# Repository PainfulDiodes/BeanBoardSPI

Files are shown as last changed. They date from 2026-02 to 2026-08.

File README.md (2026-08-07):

# BeanBoardSPI

_SPI controller in 74' logic for [BeanBoard](https://github.com/PainfulDiodes/BeanBoard) / [BeanZee](https://github.com/PainfulDiodes/BeanZee) Z80 computer._

SPI is a fast serial interface commonly used for connecting microcontrollers to peripherals like SD cards, displays and sensors.

The intent of this design is to provide access to an [RA8875](https://www.adafruit.com/product/1590) TFT panel controller and to [flash memory modules](https://www.adafruit.com/product/5635) on my Z80 homebrew computer. The [Marvin](https://github.com/PainfulDiodes/marvin) monitor program provides software support for this configuration.

For background, please see the [accompanying blog posts](https://painfuldiodes.wordpress.com/category/beanboardspi/).

*Thank you to those helpful folks at [PCBWay](https://pcbway.com) who sponsored this build and provided the PCBs*

&nbsp;

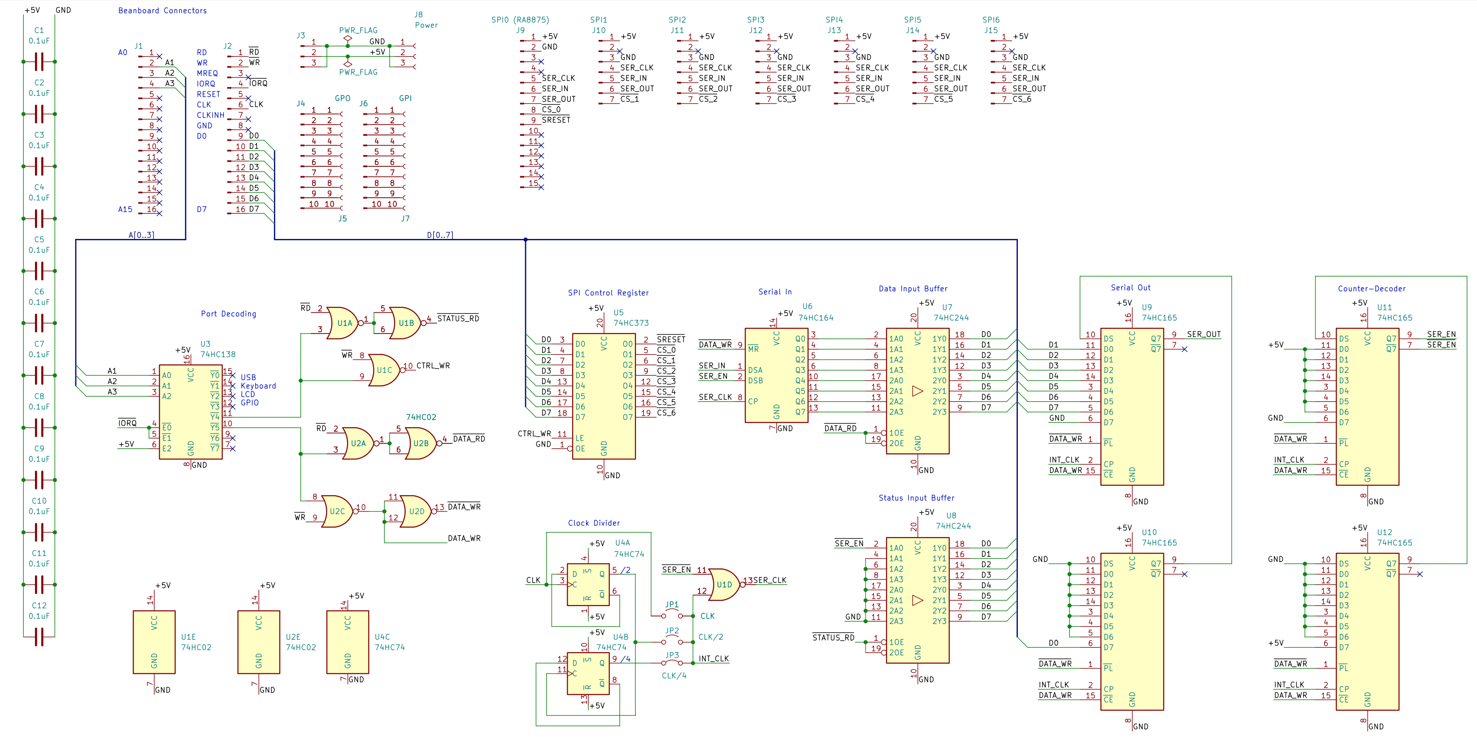
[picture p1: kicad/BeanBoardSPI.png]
beanboardspi-schematic


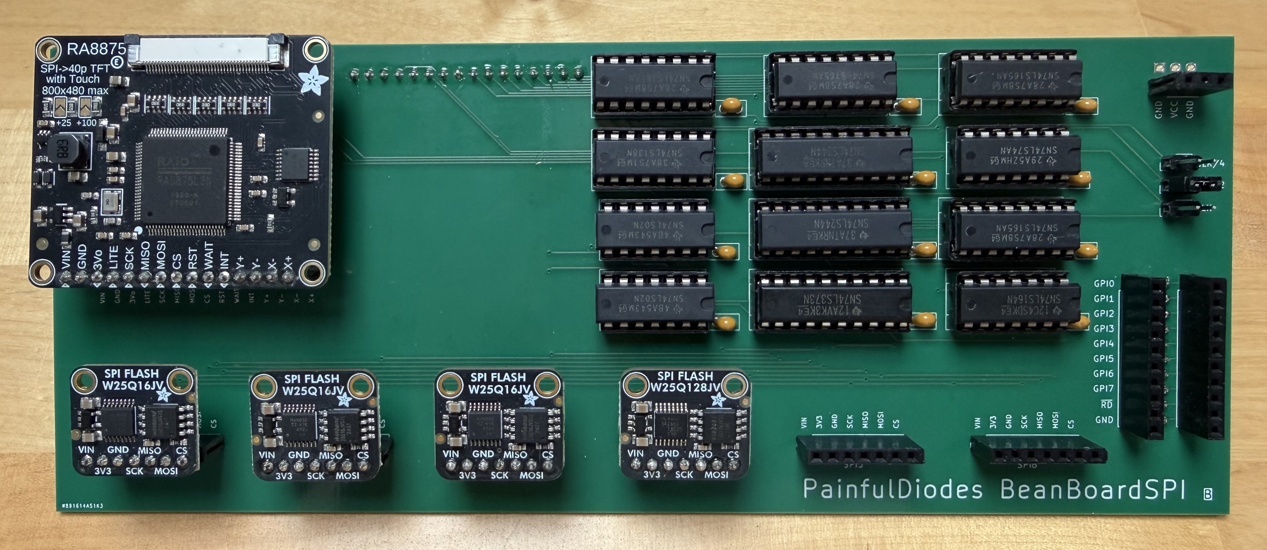
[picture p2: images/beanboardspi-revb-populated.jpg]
beanboardspi-revb-populated

BeanBoardSPI Rev B populated with Adafruit SPI modules

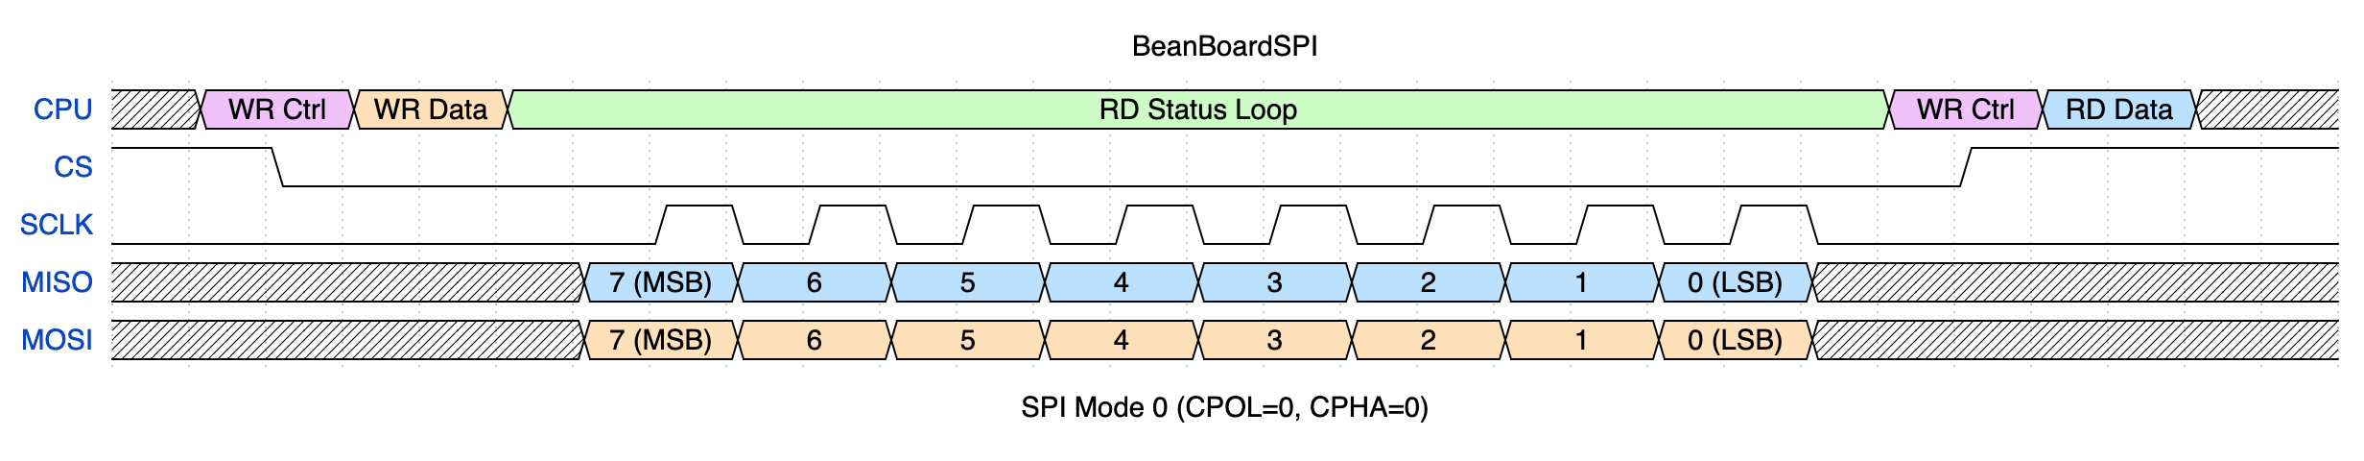
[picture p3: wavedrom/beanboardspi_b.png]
wavedrom-timing-diagram

SPI timing

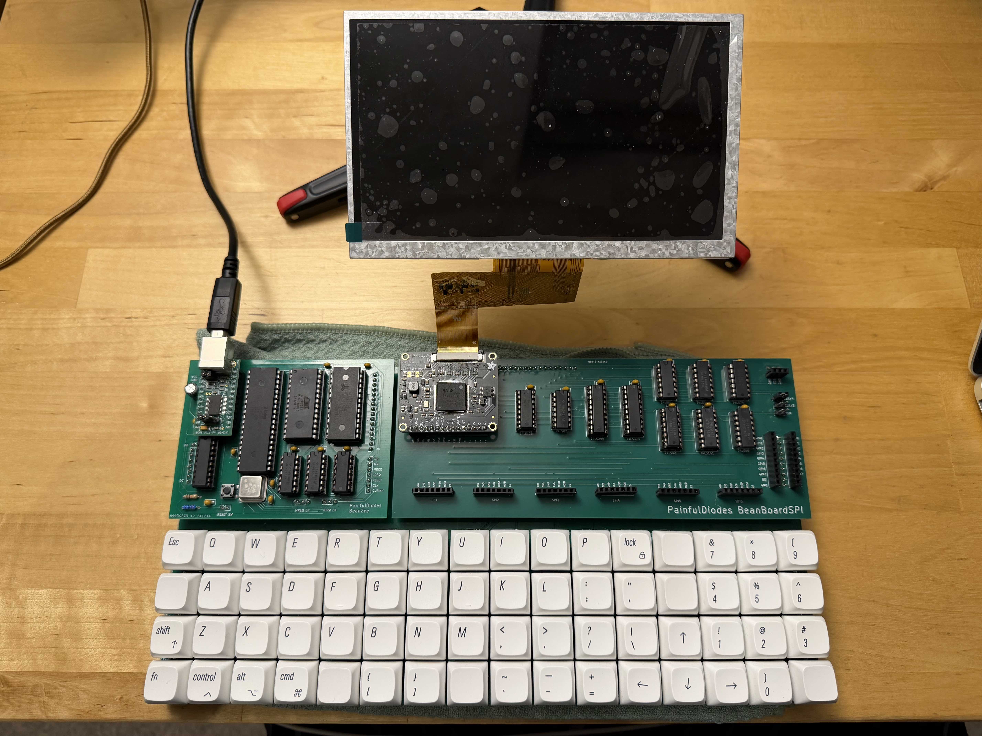
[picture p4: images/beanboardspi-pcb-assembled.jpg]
beanboard-spi-pcb-assembled

BeanBoardSPI Rev A Plugged into BeanBoard with BeanZee, and a TFT panel

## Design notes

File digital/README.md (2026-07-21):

# Digital simulations

These .dig files were designed and may be run in [Digital](https://github.com/hneemann/Digital)

Helmut Neemann's Digital is an excellent and easy-to-use digital logic designer and circuit simulator.

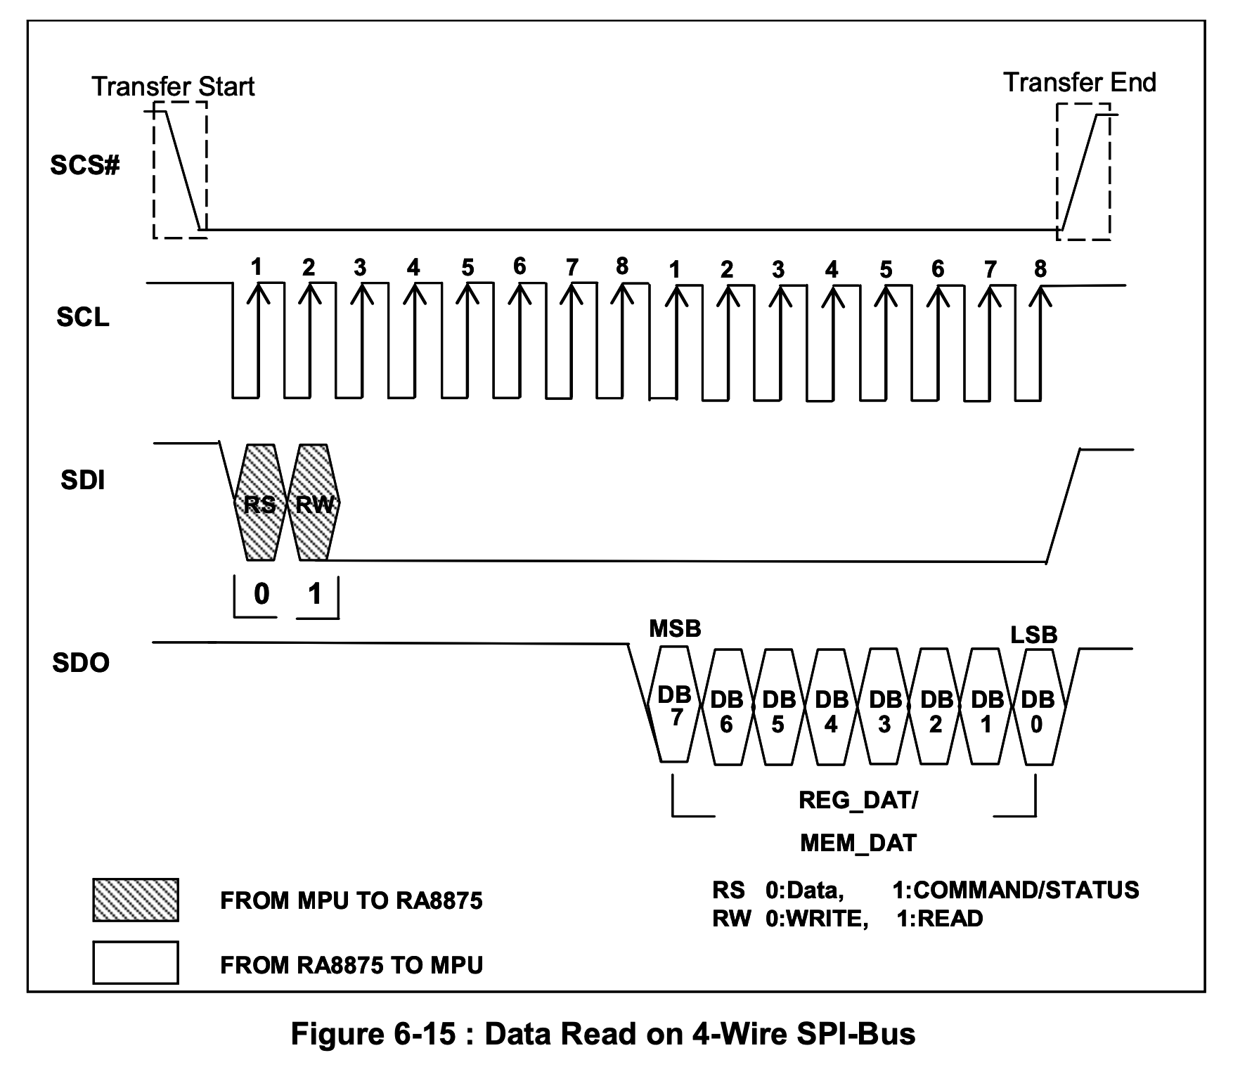
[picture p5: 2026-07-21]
images/ra8875_data_read.png

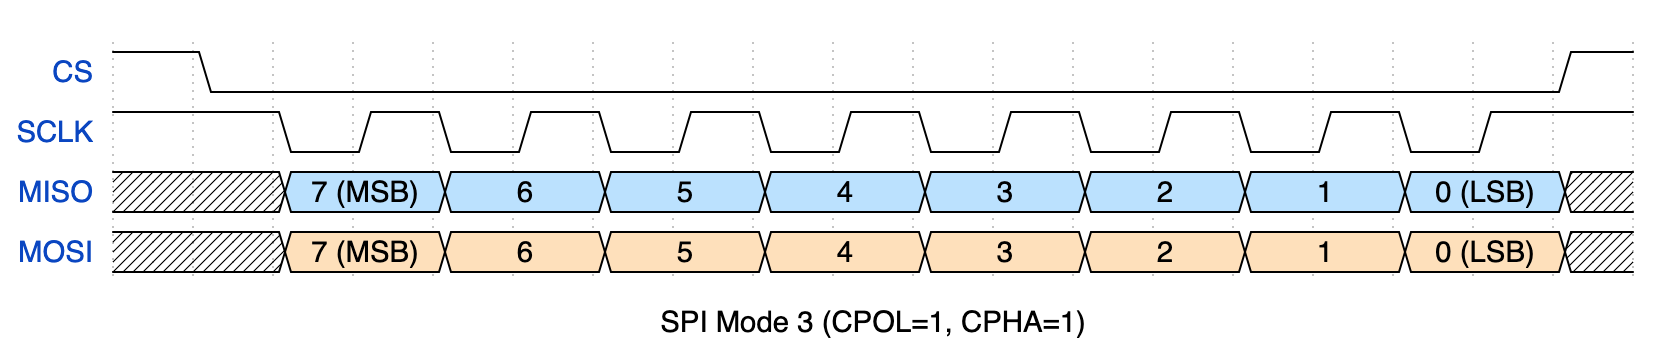
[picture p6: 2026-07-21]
wavedrom/spi_mode_3.png

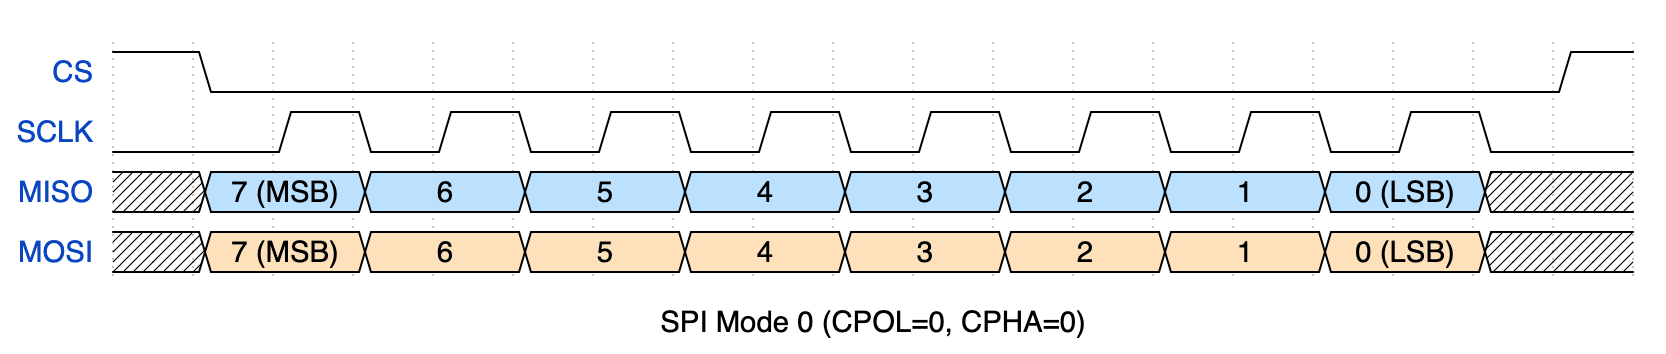
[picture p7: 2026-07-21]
wavedrom/spi_mode_0.png

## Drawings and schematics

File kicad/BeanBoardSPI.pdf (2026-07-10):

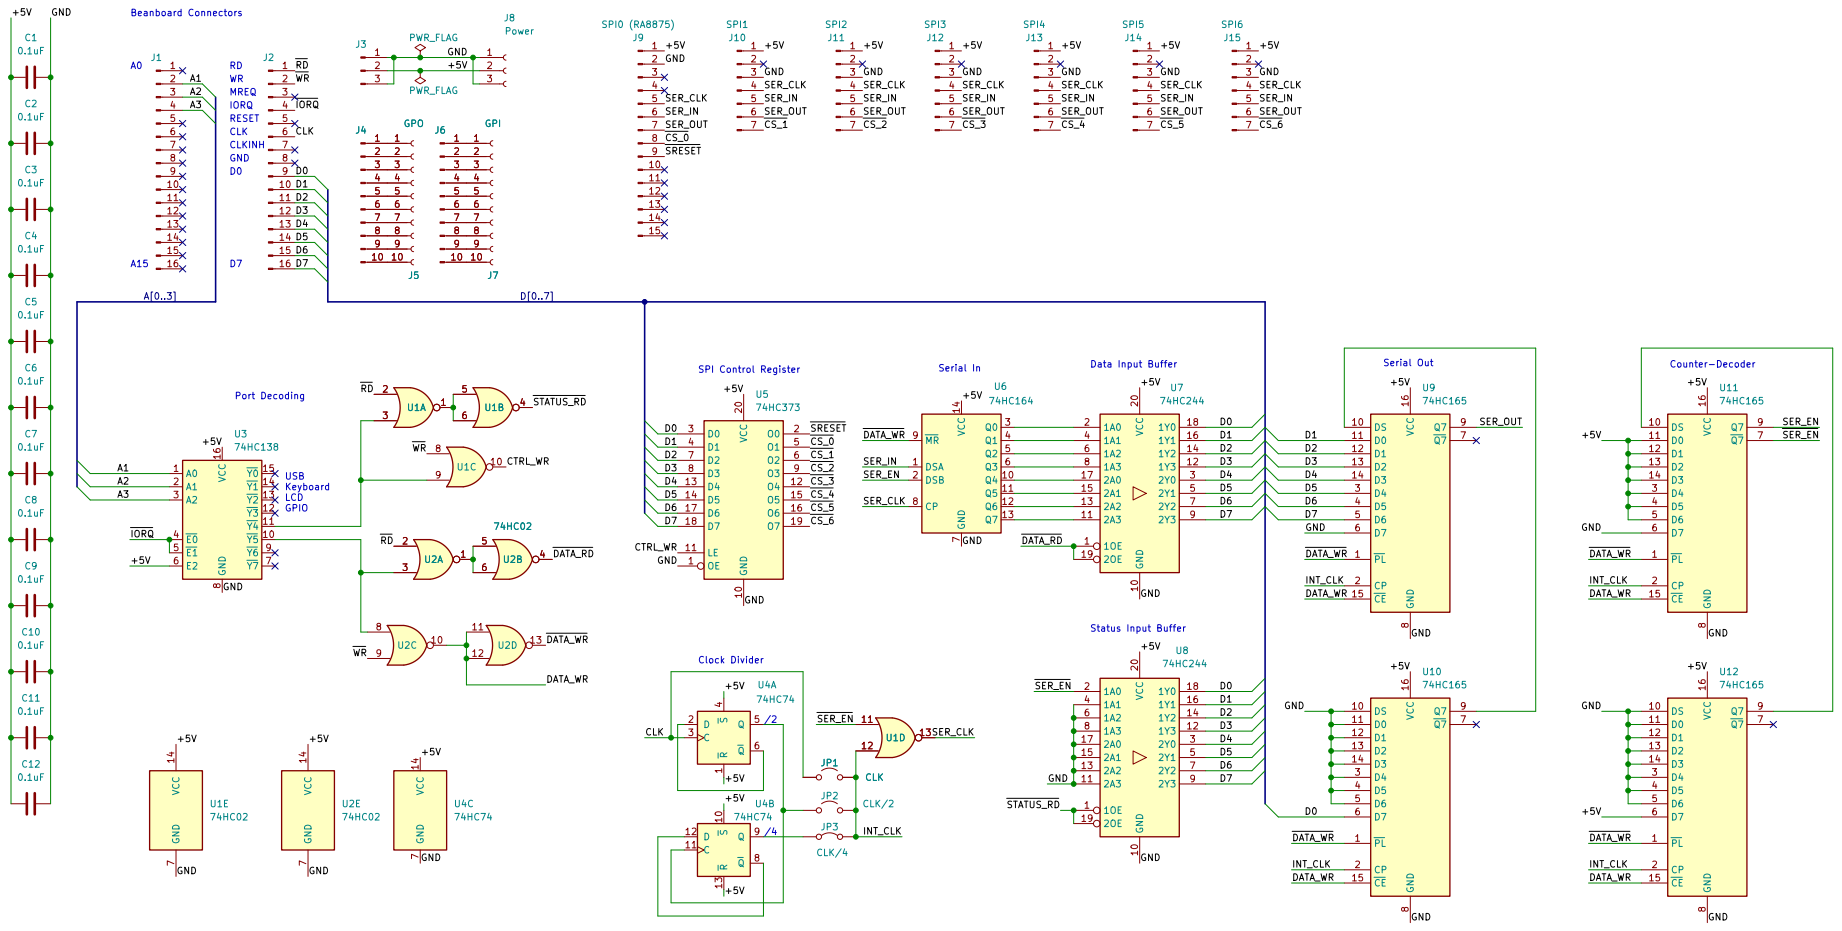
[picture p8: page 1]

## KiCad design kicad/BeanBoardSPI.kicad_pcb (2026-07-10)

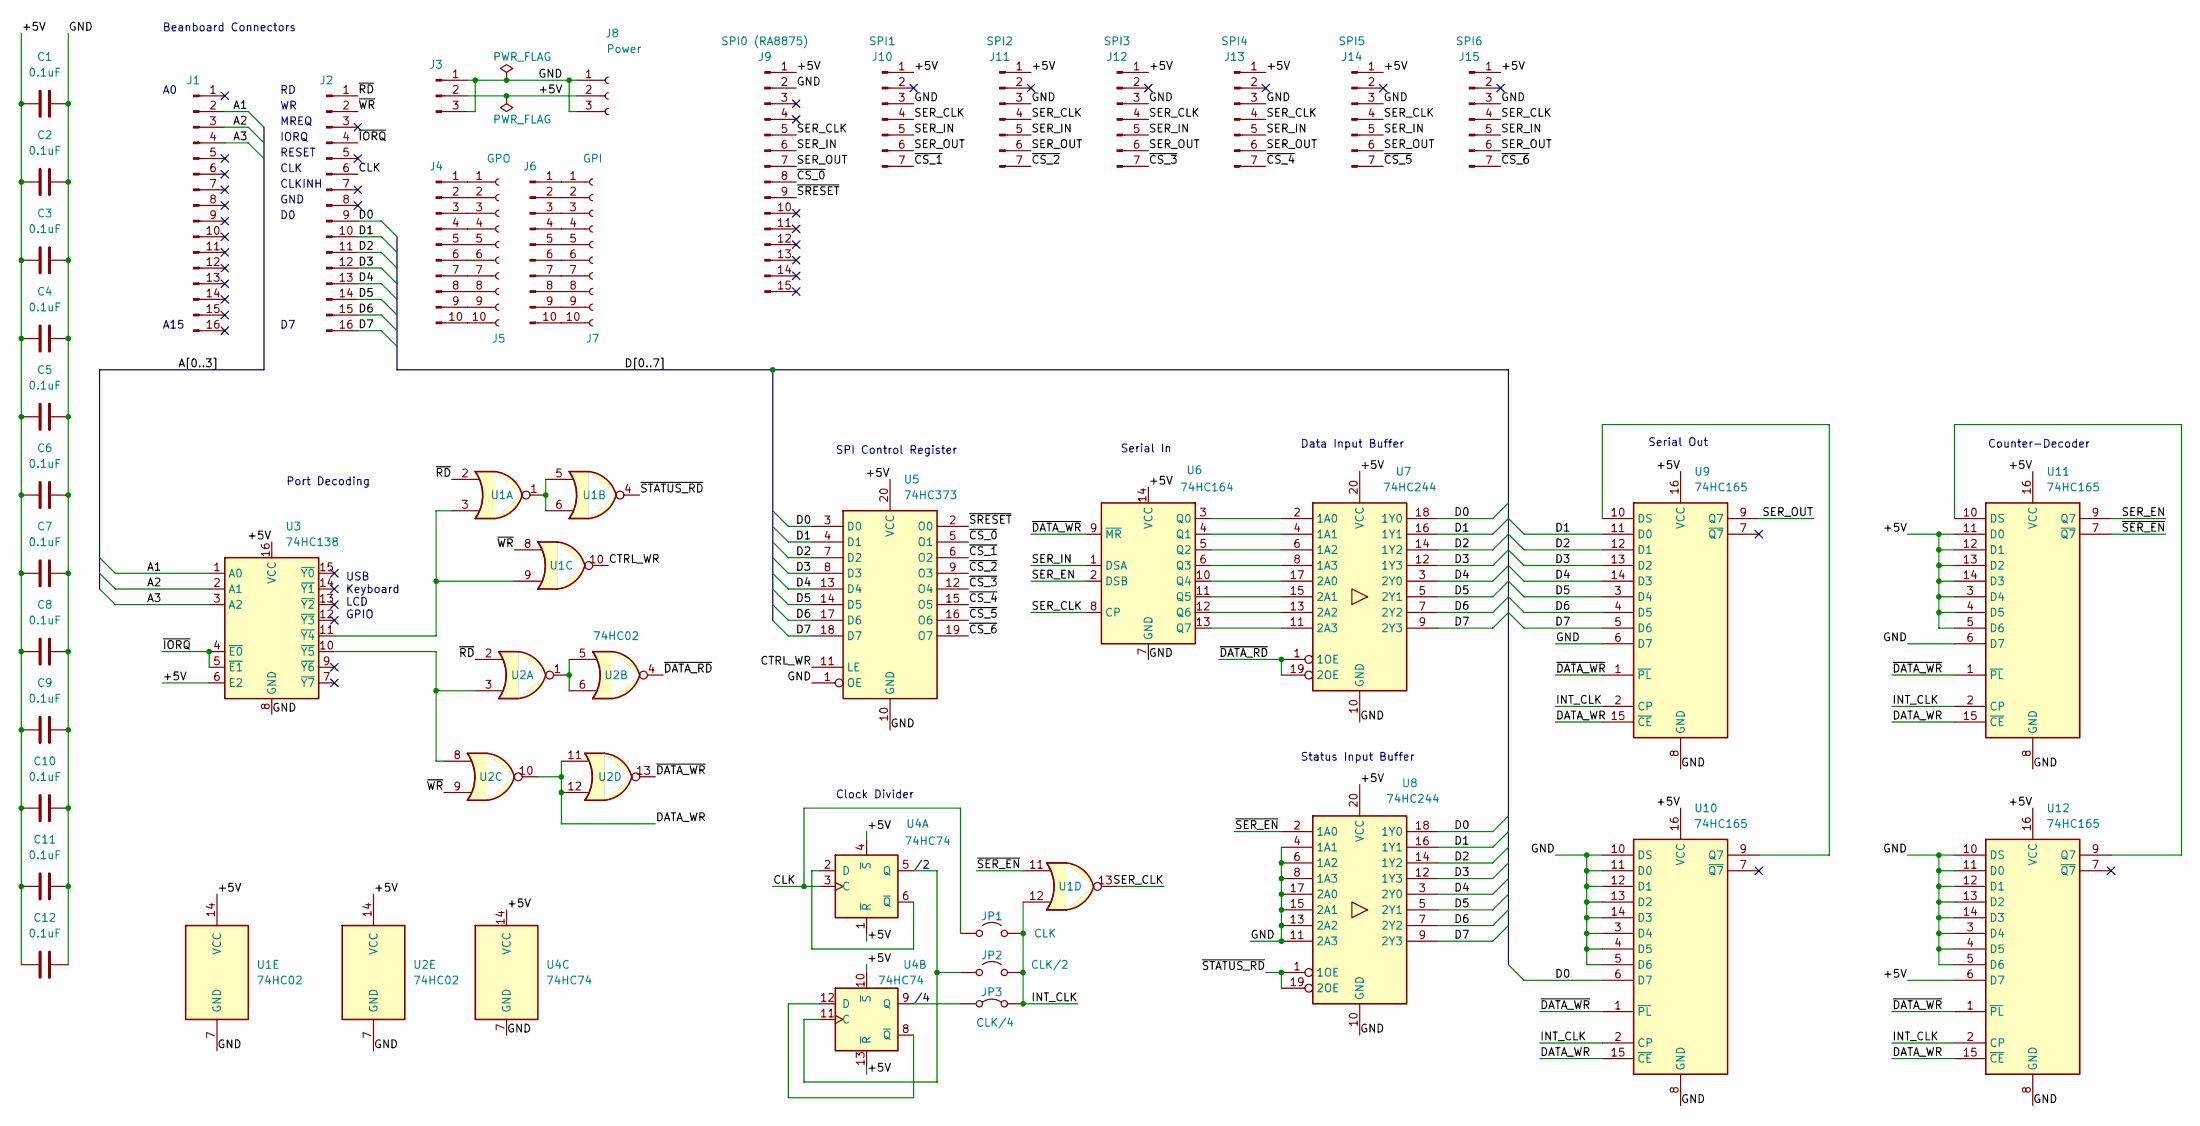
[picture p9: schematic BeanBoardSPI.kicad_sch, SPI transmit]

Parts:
C1, C2, C3, C4, C5, C6, C7, C8, C9, C10, C11, C12: 0.1uF; C_Disc_D5.0mm_W2.5mm_P2.50mm
J1, J2: Conn_01x16_Pin; PinHeader_1x16_P2.54mm_Vertical
J3: Conn_01x03_Pin; PinHeader_1x03_P2.54mm_Vertical
J4, J6: Conn_01x10_Pin; PinHeader_1x10_P2.54mm_Vertical
J5: GPO; PinSocket_1x10_P2.54mm_Vertical
J7: GPI; PinSocket_1x10_P2.54mm_Vertical
J8: Power; PinSocket_1x03_P2.54mm_Vertical
J9: SPI0 (RA8875); PinHeader_1x15_P2.54mm_Vertical
J10: SPI1; PinHeader_1x07_P2.54mm_Vertical
J11: SPI2; PinHeader_1x07_P2.54mm_Vertical
J12: SPI3; PinHeader_1x07_P2.54mm_Vertical
J13: SPI4; PinHeader_1x07_P2.54mm_Vertical
J14: SPI5; PinHeader_1x07_P2.54mm_Vertical
J15: SPI6; PinHeader_1x07_P2.54mm_Vertical
JP1: CLK; PinHeader_1x02_P2.54mm_Vertical
JP2: CLK/2; PinHeader_1x02_P2.54mm_Vertical
JP3: CLK/4; PinHeader_1x02_P2.54mm_Vertical
U1, U2: 74HC02; DIP-14_W7.62mm_Socket
U3: 74HC138; DIP-16_W7.62mm_Socket
U4: 74HC74; DIP-14_W7.62mm_Socket
U5: 74HC373; DIP-20_W7.62mm_Socket
U6: 74HC164; DIP-14_W7.62mm_Socket
U7, U8: 74HC244; DIP-20_W7.62mm_Socket
U9, U10, U11, U12: 74HC165; DIP-16_W7.62mm_Socket

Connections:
/+5V: C1.1, C2.1, C3.1, C4.1, C5.1, C6.1, C7.1, C8.1, C9.1, C10.1, C11.1, C12.1, J3.2, J8.2, J9.1, J10.1, J11.1, J12.1, J13.1, J14.1, J15.1, U1.14 (VCC), U2.14 (VCC), U3.6 (E2), U3.16 (VCC), U4.1 (~R), U4.4 (~S), U4.10 (~S), U4.13 (~R), U4.14 (VCC), U5.20 (VCC), U6.14 (VCC), U7.20 (VCC), U8.20 (VCC), U9.16 (VCC), U10.16 (VCC), U11.3 (D4), U11.4 (D5), U11.5 (D6), U11.11 (D0), U11.12 (D1), U11.13 (D2), U11.14 (D3), U11.16 (VCC), U12.6 (D7), U12.16 (VCC)
/A1: J1.2, U3.1 (A0)
/A2: J1.3, U3.2 (A1)
/A3: J1.4, U3.3 (A2)
/CLK: J2.6, JP1.1 (A), U4.3 (C)
/CTRL_WR: U1.10, U5.11 (LE)
/D0: J2.9, U5.3 (D0), U7.18 (1Y0), U8.18 (1Y0), U10.6 (D7)
/D1: J2.10, U5.4 (D1), U7.16 (1Y1), U8.16 (1Y1), U9.11 (D0)
/D2: J2.11, U5.7 (D2), U7.14 (1Y2), U8.14 (1Y2), U9.12 (D1)
/D3: J2.12, U5.8 (D3), U7.12 (1Y3), U8.12 (1Y3), U9.13 (D2)
/D4: J2.13, U5.13 (D4), U7.3 (2Y0), U8.3 (2Y0), U9.14 (D3)
/D5: J2.14, U5.14 (D5), U7.5 (2Y1), U8.5 (2Y1), U9.3 (D4)
/D6: J2.15, U5.17 (D6), U7.7 (2Y2), U8.7 (2Y2), U9.4 (D5)
/D7: J2.16, U5.18 (D7), U7.9 (2Y3), U8.9 (2Y3), U9.5 (D6)
/DATA_WR: U2.10, U2.11, U2.12, U9.15 (~CE), U10.15 (~CE), U11.15 (~CE), U12.15 (~CE)
/GND: C1.2, C2.2, C3.2, C4.2, C5.2, C6.2, C7.2, C8.2, C9.2, C10.2, C11.2, C12.2, J3.1, J3.3, J8.1, J8.3, J9.2, J10.3, J11.3, J12.3, J13.3, J14.3, J15.3, U1.7 (GND), U2.7 (GND), U3.8 (GND), U4.7 (GND), U5.1 (OE), U5.10 (GND), U6.7 (GND), U7.10 (GND), U8.4 (1A1), U8.6 (1A2), U8.8 (1A3), U8.10 (GND), U8.11 (2A3), U8.13 (2A2), U8.15 (2A1), U8.17 (2A0), U9.6 (D7), U9.8 (GND), U10.3 (D4), U10.4 (D5), U10.5 (D6), U10.8 (GND), U10.10 (DS), U10.11 (D0), U10.12 (D1), U10.13 (D2), U10.14 (D3), U11.6 (D7), U11.8 (GND), U12.3 (D4), U12.4 (D5), U12.5 (D6), U12.8 (GND), U12.10 (DS), U12.11 (D0), U12.12 (D1), U12.13 (D2), U12.14 (D3)
/INT_CLK: JP1.2 (B), JP2.2 (B), JP3.2 (B), U1.12, U9.2 (CP), U10.2 (CP), U11.2 (CP), U12.2 (CP)
/SER_CLK: J9.5, J10.4, J11.4, J12.4, J13.4, J14.4, J15.4, U1.13, U6.8 (CP)
/SER_EN: U6.2 (DSB), U11.9 (Q7)
/SER_IN: J9.6, J10.5, J11.5, J12.5, J13.5, J14.5, J15.5, U6.1 (DSA)
/SER_OUT: J9.7, J10.6, J11.6, J12.6, J13.6, J14.6, J15.6, U9.9 (Q7)
/~CS_0: J9.8, U5.5 (O1)
/~CS_1: J10.7, U5.6 (O2)
/~CS_2: J11.7, U5.9 (O3)
/~CS_3: J12.7, U5.12 (O4)
/~CS_4: J13.7, U5.15 (O5)
/~CS_5: J14.7, U5.16 (O6)
/~CS_6: J15.7, U5.19 (O7)
/~DATA_RD: U2.4, U7.1 (1OE), U7.19 (2OE)
/~DATA_WR: U2.13, U6.9 (~MR), U9.1 (~PL), U10.1 (~PL), U11.1 (~PL), U12.1 (~PL)
/~IORQ: J2.4, U3.4 (~E0), U3.5 (~E1)
/~RD: J2.1, U1.2, U2.2
/~SER_EN: U1.11, U8.2 (1A0), U11.7 (~Q7)
/~SRESET: J9.9, U5.2 (O0)
/~STATUS_RD: U1.4, U8.1 (1OE), U8.19 (2OE)
/~WR: J2.2, U1.8, U2.9
unnamed: J4.1, J5.1
unnamed: J4.2, J5.2
unnamed: J4.3, J5.3
unnamed: J4.4, J5.4
unnamed: J4.5, J5.5
unnamed: J4.6, J5.6
unnamed: J4.7, J5.7
unnamed: J4.8, J5.8
unnamed: J4.9, J5.9
unnamed: J4.10, J5.10
unnamed: J6.1, J7.1
unnamed: J6.2, J7.2
unnamed: J6.3, J7.3
unnamed: J6.4, J7.4
unnamed: J6.5, J7.5
unnamed: J6.6, J7.6
unnamed: J6.7, J7.7
unnamed: J6.8, J7.8
unnamed: J6.9, J7.9
unnamed: J6.10, J7.10
unnamed: JP2.1 (A), U4.5 (Q), U4.11 (C)
unnamed: JP3.1 (A), U4.9 (Q)
unnamed: U1.1, U1.5, U1.6
unnamed: U2.1, U2.5, U2.6
unnamed: U1.3, U1.9, U3.11 (~Y4)
unnamed: U2.3, U2.8, U3.10 (~Y5)
unnamed: U4.2 (D), U4.6 (~Q)
unnamed: U4.8 (~Q), U4.12 (D)
unnamed: U6.3 (Q0), U7.2 (1A0)
unnamed: U6.4 (Q1), U7.4 (1A1)
unnamed: U6.5 (Q2), U7.6 (1A2)
unnamed: U6.6 (Q3), U7.8 (1A3)
unnamed: U6.10 (Q4), U7.17 (2A0)
unnamed: U6.11 (Q5), U7.15 (2A1)
unnamed: U6.12 (Q6), U7.13 (2A2)
unnamed: U6.13 (Q7), U7.11 (2A3)
unnamed: U9.10 (DS), U10.9 (Q7)
unnamed: U11.10 (DS), U12.9 (Q7)

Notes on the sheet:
Status Input Buffer
A15
Port Decoding
USB Keyboard LCD GPIO
SPI Control Register
RESET
Serial In
MREQ
Counter-Decoder
Clock Divider
IORQ
Beanboard Connectors
CLKINH
Data Input Buffer
CLK
GND
Serial Out

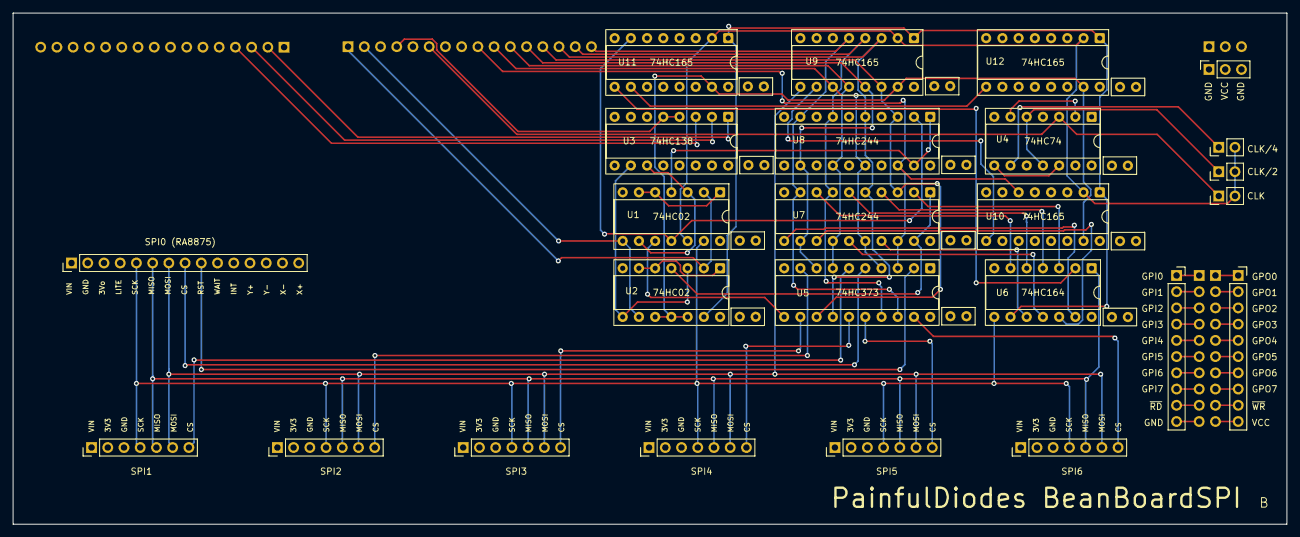
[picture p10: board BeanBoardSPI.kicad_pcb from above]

Board: 4 copper layers, 199.4 x 80.0 mm, 42 parts (0 on the bottom side), 74 nets.

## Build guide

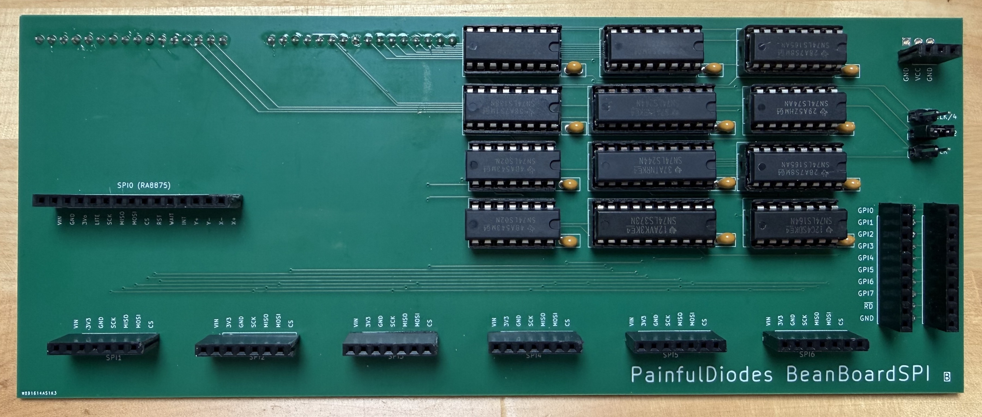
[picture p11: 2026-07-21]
images/beanboardspi-revb-assembled.jpg

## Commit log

2026-01-19 initial commit
    copied from experiment, and minor changes
    [BeanBoardSPI.kicad_sch]
2026-06-03 reset design for prototype 2
    [BeanBoardSPI-B_Cu.gbr, BeanBoardSPI-B_Mask.gbr, BeanBoardSPI-B_Paste.gbr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]
2026-06-04 Update BeanBoardSPI.dig
    added Z80 and SPI Control Register
2026-06-04 Update BeanBoardSPI.dig
    wired up the output register to the Z80 data bus
2026-06-10 Upgraded KiCAD 10.0.1
    [BeanBoardSPI.kicad_pcb, BeanBoardSPI.kicad_sch]
2026-06-11 align labels between simulation and schematic
    [BeanBoardSPI.kicad_sch]
2026-06-12 schematic files tidy
2026-06-18 Update BeanBoardSPI.kicad_sch
    added status input buffer and port decoding logic
    [BeanBoardSPI.kicad_sch]
2026-06-18 rationalised fro chip count
    replaced interters with NORs
    [BeanBoardSPI.kicad_sch]
2026-06-18 Update BeanBoardSPI.kicad_pcb
    mounting hole
    [BeanBoardSPI.kicad_pcb]
2026-06-19 schematic
    tidy footprints symbols
    [BeanBoardSPI.kicad_sch]
2026-06-19 schematic
    remove unused libraries
    [BeanBoardSPI.kicad_sch]
2026-06-19 schematic
    update project libs
    [BeanBoardSPI.kicad_sch]
2026-06-20 schematic
    renumber components
    [BeanBoardSPI.kicad_pcb, BeanBoardSPI.kicad_sch]
2026-06-20 layout
    footprints
    [BeanBoardSPI.kicad_pcb, BeanBoardSPI.kicad_sch]
2026-06-20 schematic / layout
    tidy
    [BeanBoardSPI.kicad_pcb, BeanBoardSPI.kicad_sch]
2026-06-20 layout / schematic
    position components
    [BeanBoardSPI.kicad_pcb, BeanBoardSPI.kicad_sch]
2026-06-20 layout
    silk screen
    [BeanBoardSPI.kicad_pcb]
2026-06-20 layout / schematic
    clock divider labelling
    [BeanBoardSPI.kicad_pcb, BeanBoardSPI.kicad_sch]
2026-06-21 Update BeanBoardSPI.kicad_pcb
    cap positioning
    [BeanBoardSPI.kicad_pcb]
2026-06-21 Update BeanBoardSPI.kicad_pcb
    tracks - data
    [BeanBoardSPI.kicad_pcb]
2026-06-21 Update BeanBoardSPI.kicad_pcb
    data / ser data tracks
    [BeanBoardSPI.kicad_pcb]
2026-07-21 move gerber zip
2026-08-07 Revise README for BeanBoardSPI project
    Updated project title and clarified SPI controller purpose.
